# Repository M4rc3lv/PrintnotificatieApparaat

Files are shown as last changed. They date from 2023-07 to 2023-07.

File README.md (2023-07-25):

# PrintnotificatieApparaat
Device that sends me a push message everytime a 3D printer completes a printjob.   
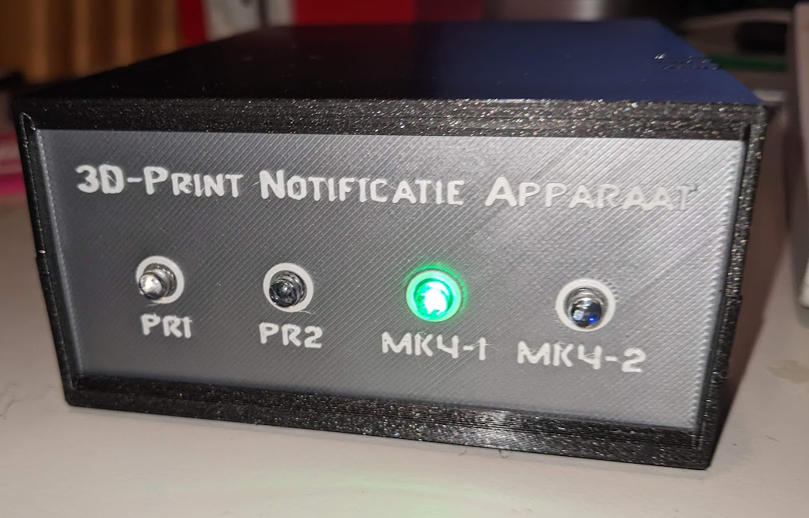
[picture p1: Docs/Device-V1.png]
Version 1

Features since V2:
- Include name of file and name of printer in message.
- Works with 1 or more 3D printers (I use it for 5 printers).
- Also sends an alert when one of the 3D printers is waiting for a filamant change.
- Works with Prusa MK4, MINI printers and every Octoprint printer (like my MK3's).

This projects consists of a D1 Mini (ESP8266 based MCU) that is always on and monitors my 3D printers. Whenever a job on a 3D printer completes, the system sends me an email. Version 2 uses a ESPDuino (but you can use any ESP8266 MCU) and has a NeoPixel LED-strip and a buzzer. See the [schematic](https://github.com/M4rc3lv/PrintnotificatieApparaat/blob/main/3Schematic.png).

## Setup
1. Place the `sendmail.php` file on a webserver.
2. Upload the edited `.ino` file to the ESPDuino or other ESP8266. Edit the file by adding your 3D printers. Every printer that is connected to Octoprint/Octopi is supported and also the Prusa MK4 and Prusa MINI (which are connected directly to your network, without Octoprint) is supported. Compile in the Arduino IDE with Board set to "ESPino (ESP-12 Module)".
3. Power up a 3D printer and you'll receive an email as soon as the print is ready or when you need to change the filament.

## Libraries
The ESPduino/D1 Mini file uses standard ESP8266 libraries and a special JSON library that can be found [here](https://github.com/bblanchon/ArduinoJson.git). Can also be installed using the Arduino IDE itself.
\
\
**Example of a message:**
<table><tr><td>
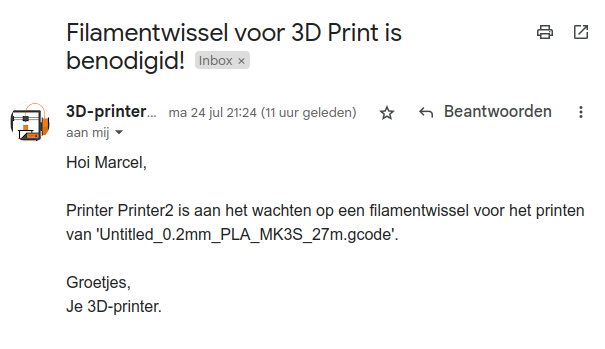
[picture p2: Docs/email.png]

</td></tr></table>

**Version 2 of the device:**
\


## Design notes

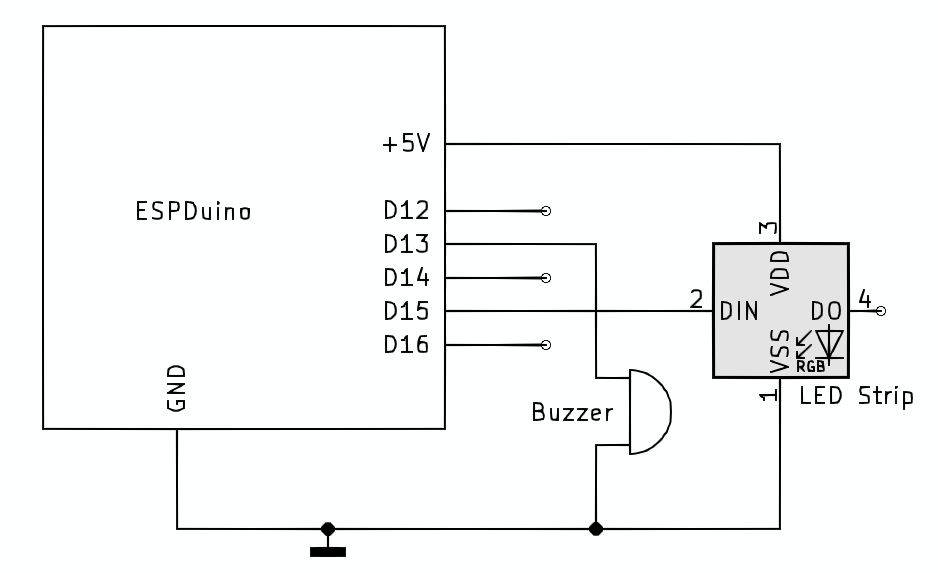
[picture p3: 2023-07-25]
Docs/3Schematic.png

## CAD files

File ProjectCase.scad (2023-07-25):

$fn=200;

Bottom=1;
Top=1;
Frontpanel=1;
Backpanel=1;
Foot=1;

WIDTH=140;
HEIGHT=50;
DEPTH=120;

XPP=1.4;

if(Foot) {
 cylinder(d=3.8,h=3);
 translate([0,0,3]) cylinder(d=14,h=3);
}

if(Backpanel) translate([0,DEPTH-6.2,1])  {
 color("white") difference() {
  cube([WIDTH-0.6,3,HEIGHT-2]); 
  // USB-aansluiting ESPDuino
  translate([60,-4,3]) cube([13,20,12]);
 }
 //2,6 5,2 
}

if(Frontpanel) translate([0,3,1])  {
 
 D=16.6*4;
 difference() {
  color("white") cube([WIDTH-0.6,3,HEIGHT-2]);
  translate([WIDTH/2-D/2,0,0])
  for(i=[0:1:4]) {   
   translate([16.6*i-2.7,0,0]) translate([0,-1,20])cube([5.4,10,5.4]);  
  }
   
  translate([(WIDTH-2)/2-D/2,0,0]) {
   // LED 0 en LED 6 (niet zichtbaar en niet in gebruik)
   translate([-16.6-2.7,2.4,0]) translate([0,-1,20])cube([5.4,10,5.4]);  
   translate([16.6*5-2.7,2.4,0]) translate([0,-1,20])cube([5.4,10,5.4]);  
  }
 
 }// diff
   
  color("grey")translate([7,0,35])rotate([90,0,0])
   linear_extrude(height=0.6) text(size=7,"3D-Print Notifier", halign="left",
     //font="Nimbus Sans Narrow:style=Bold");
  font="SF Atarian System Extended");

  translate([WIDTH/2-D/2-2.7,3,0]) {
   color("grey")translate([16.5*0+2.7,-3,14])rotate([90,30,0])
    linear_extrude(height=0.6) text(size=4,"P1", halign="center", valign="center",
     font="Arial Black");
   color("grey")translate([16.5*1+2.7,-3,14])rotate([90,30,0])
    linear_extrude(height=0.6) text(size=4,"P2", halign="center", valign="center",
     font="Arial Black");
   color("grey")translate([16.5*2+2.7,-3,14])rotate([90,30,0])
    linear_extrude(height=0.6) text(size=4,"MK4", halign="center", valign="center",
     font="Arial Black");
   color("grey")translate([16.5*3+2.7,-3,14])rotate([90,30,0])
    linear_extrude(height=0.6) text(size=4,"MK4-2", halign="center", valign="center",
     font="Arial Black");
   color("grey")translate([16.5*4+2.7,-3,14])rotate([90,30,0])
    linear_extrude(height=0.6) text(size=4,"MINI", halign="center", valign="center",
     font="Arial Black");
  }  
 
}


if(Top) translate([0,0,HEIGHT/2+1]){
 //if(Top) translate([0,0,HEIGHT/2+1]){
 difference() {
  hull() {
   translate([0,0,HEIGHT/2-1]) rotate([-90,0,0])cylinder(d=2,h=DEPTH);
   translate([0,0,HEIGHT/2-1]) translate([WIDTH,0,0])rotate([-90,0,0])cylinder(d=2,h=DEPTH);  
   translate([-1,0,0]) cube([2,DEPTH,2]);
   translate([WIDTH-1,0,0])cube([2,DEPTH,2]);
  }
  translate([1,-1,-1]) 
   cube([WIDTH-2,DEPTH+10,HEIGHT/2-1]);
  
  // Sleuf frontpanel 
  translate([0,3,-HEIGHT/2+14])cube([WIDTH,3.4,HEIGHT/2+10]);
  // Sleuf backpanel 
  translate([0,DEPTH-6.4,-HEIGHT/2+14])cube([WIDTH,3.4,HEIGHT/2+10]);
  
  // Koeling gaten - Let op dat deze soms fout gaan bij afmetingen
  translate([WIDTH/2-50/2,20,HEIGHT/4+5])  cube([50,2,10]);  
  translate([WIDTH/2-50/2,28,HEIGHT/4+5])  cube([50,2,10]);  
  translate([WIDTH/2-50/2,36,HEIGHT/4+5])  cube([50,2,10]);  
 }//diff
 
 // Front sleeve
 translate([WIDTH,0,HEIGHT/2-1]) {
  rotate([0,180,0])difference() {
   translate([0,0,1])cube([WIDTH,3,3]);
   translate([-1,-1,4])rotate([90,0,90])cylinder(d=6,h=WIDTH+10);
  }
  rotate([0,180,0])translate([0,6.4,1])cube([WIDTH,2,5]);
 }
 // Back sleeve
 translate([0,DEPTH,HEIGHT/2-1]) {
  rotate([0,180,180])difference() {
   translate([0,0,1])cube([WIDTH,3,3]);
   translate([-1,-1,4])rotate([90,0,90])cylinder(d=6,h=WIDTH+10);
  }
  rotate([0,180,180])translate([0,DEPTH-6.4-2,1])cube([WIDTH,2,5]);
 }
 
 // Bevestigingsschroeven zijkant
 translate([1,DEPTH/5,-8]) difference() {
  cube([6,10,HEIGHT/2+8]);
  translate([-1,5,4])rotate([90,0,90])cylinder(d=3.4,h=5);
 } 
 translate([1,DEPTH-DEPTH/5,-8]) difference() {
  cube([6,10,HEIGHT/2+8]);
  translate([-1,5,4])rotate([90,0,90])cylinder(d=3.4,h=5);
 } 
 translate([WIDTH-7,DEPTH/5,-8]) difference() {
  cube([6,10,HEIGHT/2+8]);
  translate([2,5,4])rotate([90,0,90])cylinder(d=3.4,h=5);
 } 
 translate([WIDTH-7,DEPTH-DEPTH/5,-8]) difference() {
  cube([6,10,HEIGHT/2+8]);
  translate([2,5,4])rotate([90,0,90])cylinder(d=3.4,h=5);
 }   
}


if(Bottom) { 
 difference() {
  hull() {
   rotate([-90,0,0])cylinder(d=2,h=DEPTH);
   translate([WIDTH,0,0])rotate([-90,0,0])cylinder(d=2,h=DEPTH);  
   translate([-1,0,HEIGHT/2-1]) cube([2,DEPTH,2]);
   translate([-1,0,HEIGHT/2-1])translate([WIDTH,0,0])cube([2,DEPTH,2]);  
  }
  translate([1,-1,1]) cube([WIDTH-2,DEPTH+10,HEIGHT/2+10]);
      
  // Schroefgaten zijkant
  translate([-2,DEPTH/5+5,HEIGHT/2-3]) rotate([90,0,90])cylinder(d=2.6,h=5);
  translate([-5,DEPTH/5+5,HEIGHT/2-3]) rotate([90,0,90])cylinder(d=5,h=5);
  translate([-2,DEPTH-DEPTH/5+5,HEIGHT/2-3]) rotate([90,0,90])cylinder(d=2.6,h=5);
  translate([-5,DEPTH-DEPTH/5+5,HEIGHT/2-3]) rotate([90,0,90])cylinder(d=5,h=5);
  
  translate([WIDTH-2,DEPTH/5+5,HEIGHT/2-3]) rotate([90,0,90])cylinder(d=2.6,h=5);
  translate([WIDTH,DEPTH/5+5,HEIGHT/2-3]) rotate([90,0,90])cylinder(d=5,h=5);
  
  translate([WIDTH-2,DEPTH-DEPTH/5+5,HEIGHT/2-3]) rotate([90,0,90])cylinder(d=2.6,h=5);
  translate([WIDTH,DEPTH-DEPTH/5+5,HEIGHT/2-3]) rotate([90,0,90])cylinder(d=5,h=5);
  
  // Sleuven frontpanel 
  translate([0,3,0])cube([WIDTH,3.4,HEIGHT/2+10]);
  // Sleuven backpanel
  translate([0,DEPTH-6.6,0])cube([WIDTH,3.4,HEIGHT/2+10]);
  // Gaatjes voor voetjes
  translate([11,11,-2]) cylinder(d=4,h=10);
  translate([WIDTH-11,11,-2]) cylinder(d=4,h=10);
  translate([WIDTH-11,DEPTH-11,-2]) cylinder(d=4,h=10);
  translate([11,DEPTH-11,-2]) cylinder(d=4,h=10);
 }
 
 // Front sleeve
 difference() {
  translate([0,0,1])cube([WIDTH,3,3]);
  translate([-1,-1,4])rotate([90,0,90])cylinder(d=6,h=WIDTH+10);
 }
 translate([0,6.4,1])cube([WIDTH,2,5]);
 // Back
 difference() {
  translate([0,DEPTH-3,1])cube([WIDTH,3,3]);
  translate([-1,DEPTH+1,5])rotate([90,0,90])cylinder(d=6,h=WIDTH+10);
  // USB-aansluiting ESPDuino
  translate([60,DEPTH-14,3]) cube([13,20,12]);
 }
 difference() {
  translate([0,DEPTH-6.4-2,1])cube([WIDTH,2,5]); 
  // USB-aansluiting ESPDuino
  translate([60,DEPTH-14,3]) cube([13,20,12]);
 }
}

module Cube(xdim ,ydim ,zdim,rdim=1) {
 hull(){
  translate([rdim,rdim,0])cylinder(h=zdim,r=rdim);
  translate([xdim-rdim,rdim,0])cylinder(h=zdim,r=rdim);
  translate([rdim,ydim-rdim,0])cylinder(h=zdim,r=rdim);
  translate([xdim-rdim,ydim-rdim,0])cylinder(h=zdim,r=rdim);
 }
}

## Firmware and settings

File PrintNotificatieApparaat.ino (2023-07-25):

// Versie 2: voor ESPDuino met LEDstrip met voor elke printer een LED
// In de mail staat nu ook de naam van het bestand dat geprint werd.
// Compileren met Board = "ESPino (ESP-12 Module)"
// Rood: printer OFFLINE (staat uit)
// Groen: printer ONLINE en aan het printen
// Oranje: printer staat aan maar is niet aan het printen

// Buzzer: geeft in Morse (...-.) aan als een printer klaar is

#include <ESP8266WiFi.h>
#include <ESP8266WiFiMulti.h>
#include <ESP8266HTTPClient.h>
#include <ArduinoJson.h>
#include <WiFiClientSecure.h>
#include <Adafruit_NeoPixel.h>
#include <UrlEncode.h>

#define BUZZER 13

#define WIFI_SSID "Your Wifi ISSD"
#define WIFI_PASSWORD "Wifi password"

#define PRINTERTYPE_OCTOPI "OCTO"
#define PRINTERTYPE_MK4 "MK4"

#define ROOD   (LEDStrip.Color(80,0,0))
#define GROEN  (LEDStrip.Color(0,60,0))
#define BLAUW  (LEDStrip.Color(0,0,80))
#define ORANJE (LEDStrip.Color(40,20,0))

#define PRINTERTYPE_OCTOPI "OCTO"
#define PRINTERTYPE_MK4 "MK4"

// Array of all your 3D printers
// Every row (printer) has the following 4 elements:
//  Human-friendly name of printer, I address of printer, Password, Printer type (MK4 or Octopi)
// The password is the password of the user "maker" of the MK4. 
const char *Printers[]={
 "Printer1", "http://192.168.0.11/api/job", "924DCEB3BEAPI-Key8EBBCAC6CF631F",PRINTERTYPE_OCTOPI,
 "Printer2", "http://192.168.0.10/api/job", "5B9379API-KeyBB981B1C728",PRINTERTYPE_OCTOPI,
 "MK4","http://192.168.0.49:80/api/job","hdAPI-KeyDfHpN",PRINTERTYPE_MK4,
 "MK4-2","http://192.168.0.50:80/api/job","wAPI-Key",PRINTERTYPE_MK4,
 "MINI","http://192.168.0.4:80/api/job","XFMAPI-Keyg2y",PRINTERTYPE_MK4
};
const int NUMPRINTERS=sizeof(Printers) / sizeof(Printers[0])/4;

bool IsPRINTING[NUMPRINTERS];
bool IsMonitoring[NUMPRINTERS];
bool IsOranje[NUMPRINTERS];
String Files[NUMPRINTERS]; // Bewaar bestandsnamen zodat je die in de mail erbij kunt zetten later
bool IsFilamentMailVerstuurd[NUMPRINTERS];

// URL to my PHP script somewhere online that sends emails
#define WEB_MAILSENDER   "https://marcelv.net/IoT/sendmail.php"

ESP8266WiFiMulti EspDuino;
Adafruit_NeoPixel LEDStrip = Adafruit_NeoPixel(6,15, NEO_GRB + NEO_KHZ800);

void setup() {
 Serial.begin(115200);
 Serial.println("Opstarten..");
 pinMode(BUZZER,OUTPUT);
 digitalWrite(BUZZER,LOW);
 LEDStrip.begin(); 
 Alles(BLAUW); 
 WiFi.mode(WIFI_STA);
 EspDuino.addAP(WIFI_SSID, WIFI_PASSWORD);
 Serial.println("Verbonden met wifi!"); 
 AllesUit(); 
 Alles(ROOD);
 
 PieperdePiep();
}

void loop() {     
 if(EspDuino.run()== WL_CONNECTED){    
  WiFiClient client;
  HTTPClient http;   
  
  for(int i=0; i<NUMPRINTERS; i++) {         
   // This is an MK4 printer    
   http.begin(client,Printers[i*4+1]);
   http.addHeader("X-Api-Key", Printers[i*4+2]);
        
   int httpCode = http.GET();
   if(httpCode > 0) {     
    String payload = http.getString();
    DynamicJsonDocument doc(1024);
    deserializeJson(doc, payload);
    // MK4: "State":"Operational";
    // Octoprint:       
    String Status = doc["state"].as<String>();
    bool IsPrinting = Status.indexOf("Printing")>=0; 
    IsOranje[i]=Status.indexOf("Operational")>=0; 
    
    if(IsPrinting) {
     bool IsWaiting=IsWaitingForColourChange(i);
     if(IsWaiting && !IsFilamentMailVerstuurd[i]) {
      SendMail(Printers[i*4],Files[i].c_str(),true);   
      IsFilamentMailVerstuurd[i]=true; 
     }
     
     IsMonitoring[i]=IsPRINTING[i]=true; ZetLEDKleur(i+1,GROEN);
     String s = doc["file"]["name"].as<String>(); // MK4 en MINI
     if(s=="null") s=doc["job"]["file"]["name"].as<String>(); // Octoprint
     Files[i]=s;             
    }
    else {ZetLEDKleur(i+1,IsOranje[i]? ORANJE : ROOD); IsFilamentMailVerstuurd[i]=false;} 
    if(!IsPrinting && IsMonitoring[i]) {
     // Print is klaar: verstuur alert
     IsMonitoring[i]=false; 
     IsPRINTING[i]=false;
     SendMail(Printers[i*4],Files[i].c_str(),false);    
     Files[i]="";
    }
   } 
   else {
    // MK4/MINI-Printer staat uit of Octopi niet bereikbaar 
    IsPRINTING[i]=false;
    ZetLEDKleur(i+1,ROOD);
    Offline(i);
    IsOranje[i]=false;
   }
   http.end();

  }//printers loop    
 }//Is Connected

 for(int p=0; p<NUMPRINTERS; p++) 
  ZetLEDKleur(p+1,IsPRINTING[p]? GROEN : IsOranje[p]? ORANJE : ROOD); 

 delay(10000);
}

void PieperdePiep() {
 // Morse letter V! ...-.
 for(int i=0; i<3; i++) {
  digitalWrite(BUZZER,HIGH);
  delay(80);
  digitalWrite(BUZZER,LOW);delay(80);
 }
 digitalWrite(BUZZER,HIGH);
 delay(240);
 digitalWrite(BUZZER,LOW);delay(80);
 digitalWrite(BUZZER,HIGH);
 delay(80);
 digitalWrite(BUZZER,LOW); 
}

void ZetLEDKleur(int IX,int Kleur) {
 LEDStrip.setPixelColor(IX,Kleur);
 LEDStrip.show();
}

void Offline(int PrinterIX) { 
 Serial.printf("Printer %s is offline.",Printers[PrinterIX*4]);
 Serial.println();
}

bool IsWaitingForColourChange(int PrinterIX) {
 static double PrevCompletion[NUMPRINTERS];
 String URL = Printers[PrinterIX*4+1];
    
 if(Printers[PrinterIX*4+3]==PRINTERTYPE_MK4) { 
  // Prusa printer
  URL.replace("job","printer");
  WiFiClient client; 
  HTTPClient http;   
  http.begin(client,URL);
  http.addHeader("X-Api-Key", Printers[PrinterIX*4+2]);
  int code=http.GET(); 
  String payload = http.getString();
  DynamicJsonDocument doc(1024);
  deserializeJson(doc, payload);
  http.end();
  return doc["telemetry"]["material"].as<String>()=="---";
 }
 else {
  // Octopi printer - we kunnen alleen de temperatuur bekijken om te zien of er een colour change nodig is
  // http://192.168.0.10:80/api/printer?history=true&limit=10

 /*Kijk naar progress.completion en naar progress.printtime
 Indien printtime>0 DAN pas kijken naar compltion (zodat hij niet meteen ah begin mailt)
 compltion is een double
 COMPLETION Verandert elke keer. Is getest met ene print van 2 dagen lang*/
  WiFiClient client; 
  HTTPClient http;   
  http.begin(client,URL);
  http.addHeader("X-Api-Key", Printers[PrinterIX*4+2]);
  int code=http.GET(); 
  String payload = http.getString();
  DynamicJsonDocument doc(1024);
  deserializeJson(doc, payload);
  http.end();
  
  int pt=doc["progress"]["printTime"];
  Serial.print("pt=");Serial.println(pt);
  if(pt>0) {
   double completion = doc["progress"]["completion"];

   Serial.printf("%lf %lf\r\n",completion,PrevCompletion[PrinterIX]);
   
   if(completion==PrevCompletion[PrinterIX]) {
    PrevCompletion[PrinterIX]=completion;
    return true;
   }
   PrevCompletion[PrinterIX]=completion;
  }    
 }
 return false;
}

void SendMail(const char *PrinterName,const char *Bestand,bool ColChange) {
  WiFiClientSecure client;
  client.setInsecure(); 
  
  String Url(WEB_MAILSENDER);   
  Url+="?printer="+String(PrinterName)+"&file="+urlEncode(Bestand);
  if(ColChange) Url+="&colorchange=1";
  HTTPClient http;   
  http.begin(client,Url);
  http.GET();
  String payload = http.getString();
  Serial.println(payload);
  http.end();

  PieperdePiep();
}

void AllesUit() {
 Alles(0);
}

void Alles(int Kleur) {
 LEDStrip.clear();
 for(int i=1; i<=NUMPRINTERS; i++) // Eerste LED (LED 0) wordt niet gebruikt
  LEDStrip.setPixelColor(i,Kleur);
 LEDStrip.show();
}

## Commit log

2023-07-22 Bugfix Octopi printers
2023-07-23 Opstarten: laat LED's even knipperen
2023-07-23 Project case (OpenScad)
    [ProjectCase.scad]
2023-07-23 Laat LED's knipperen zodat je weet dat hij nog werkt
2023-07-24 Versie 2: met LED-strip i.p.v. losse LED's en Buzzer
    // Versie 2: voor ESPDuino met LEDstrip met voor elke printer een LED
    // In de mail staat nu ook de naam van het bestand dat geprint werd.
    // Compileren met Board = "ESPino (ESP-12 Module)"
    // Rood: printer OFFLINE (staat uit)
    // Groen: printer ONLINE en aan het printen
    // Oranje: printer staat aan maar is niet aan het printen
    [PrintNotificatieApparaat.ino]
2023-07-24 Bestandsnaam van printjob in e-mailnotificatie
2023-07-25 Versie 2 met LED-strip.scad
    [ProjectCase.scad]
2023-07-25 Alert indien printer staat te wachten op filamentwijziging
2023-07-25 Nieuwe hardware: LED strip en Buzzer
    [PrintNotificatieApparaat.ino]
